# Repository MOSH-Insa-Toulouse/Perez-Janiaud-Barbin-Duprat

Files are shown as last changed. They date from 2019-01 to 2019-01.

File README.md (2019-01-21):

 __   __         _______  _______  __   __ 
|  |_|  |       |       ||       ||  | |  |
|       | ____  |   _   ||  _____||  |_|  |
|       ||____| |  | |  || |_____ |       |
|       |       |  |_|  ||_____  ||       |
| ||_|| |       |       | _____| ||   _   |
|_|   |_|       |_______||_______||__| |__|

/* Presentation of The RC Boat project */

Please make sure that you have all the following file :
	- Arduino Code (.ino)
	- MIT app inventor .apk file
	- 3D plan of the Boat with the .stl extension (made with Fusion360)
	- kicad file for the hardware part
	- Powerpoint presentation
	- Readme.md

/* Boat installation */

1. 3D printing of the different boat part :
	- Keep the proportion between all pieces (we printed the boat with a legnth or 27cm, the maximum possible with our 3D printer)
	- add a hole in the shell, for the motor axe

2. Motor/propeller axis
	- Our best solution was to buy a long metal tube. long enough for the motor to be over the flotation level.
	- The motor axis goes throught the tube. This way the water does not go into the boat
	
3. Rudder control
	- We extended the servomotor axis and added another metal axis to transmit the movement. (see slides)

4. Hardware
	- Follow the Kicad diagramms to place the different part
	- For a better result the PCB shield can be printed
	- Some amelioration can be made :
		- using a more powerfull motor (Brushless for waterproofing and power, ...) 
		- Changing the transistor to a MOSFET to handle higher current
		- Using a tension divider bridge to reduce the tension from 5v to 3.3V on the TX/RX pin of the HC05 BT module

/* Software */
The software is divided into two part:
	- The android application to communicate with the arduino uno and send control for the speed and position
	- The arduino software to recieve the instruction and control the hardware
Both should be used in parralel

/* Credits */
Property of Perez Sarah, Barbin Laure, Janiaud Corentin (with the mental support of Duprat Leo -- Computer Starter and Door Holder --)

 __________________________________
|                                  |
Don't compare your progress
to that of someone else
Everyone works at different speeds
You're doing great and I love you
|__________________________________|
(\__/) ||
(•?•) ||
/   ?

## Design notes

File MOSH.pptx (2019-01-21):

## Projet M-OSH

Bateau Télécommandé

15 janvier 2019
Janiaud Corentin - Perez Sarah - Duprat Léo - Barbin Laure

## Sommaire

- Présentation du projet
- Description Hardware
- Description Software
- Montage du bateau
- Démonstration
- Conclusion

## I - Présentation du Projet

Projet :
Bateau télécommandé par bluetooth
Cahier des charges :
- Bateau + mécanique
- Circuit Hardware (Arduino UNO)
- Application Android de commande
- Software

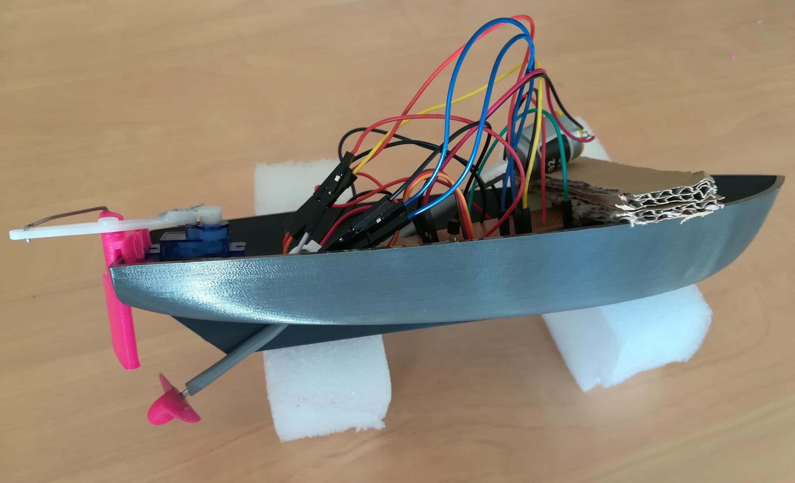
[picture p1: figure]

## II - HARDWARE - COMPOSANTS PRINCIPAUX

Mouvements du bateau :
- Avant
  - Moteur DC
  - Hélice

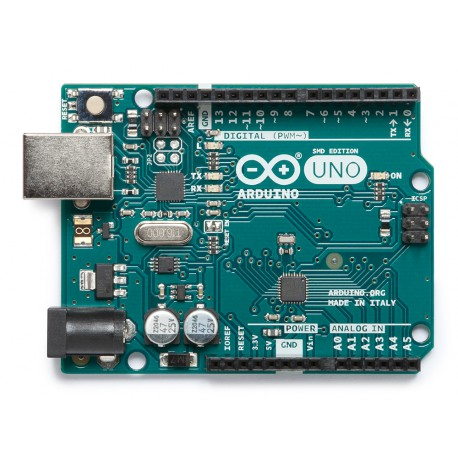
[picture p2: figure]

Arduino UNO

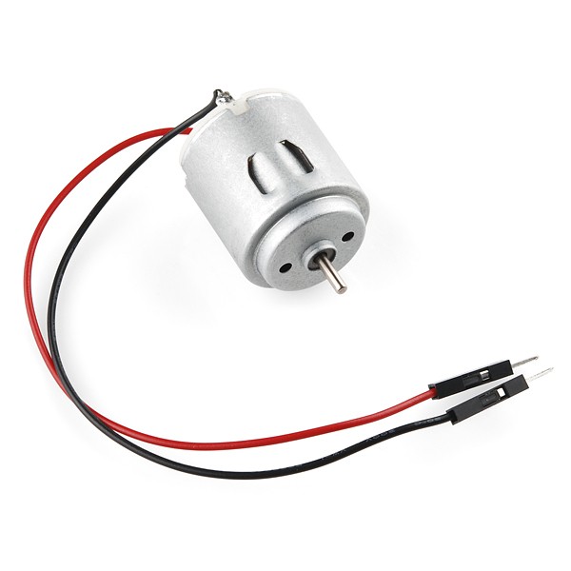
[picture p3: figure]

Moteur DC
⇾ Rotation de l’hélice

## II - HARDWARE - COMPOSANTS PRINCIPAUX

Mouvements du bateau :
- Orientation latérale
  - Gouvernail
  - Servomoteur

Servo-Moteur
⇾ Orientation du gouvernail

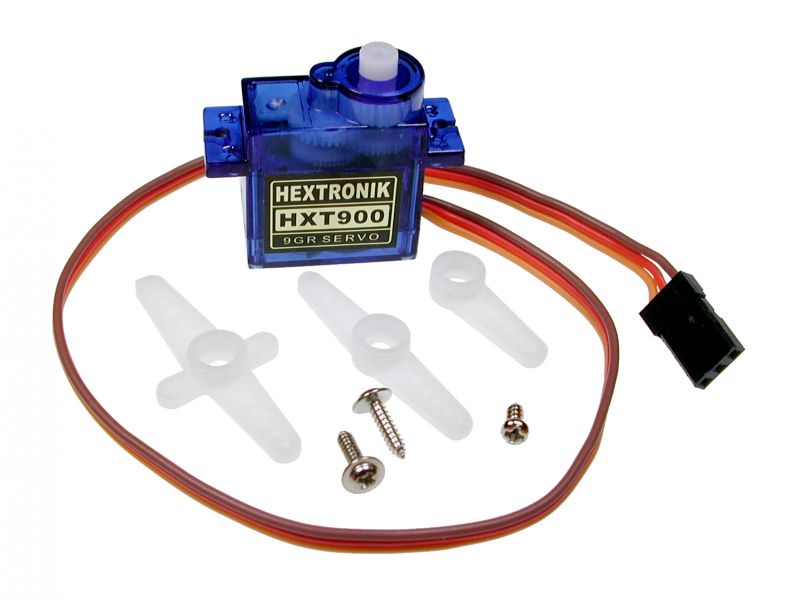
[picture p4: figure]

## II - HARDWARE - COMPOSANTS PRINCIPAUX

Communication avec Android :
- Module Bluetooth

Module HC-05
⇾ Communication bluetooth avec le smartphone

Alimentation embarquée :
- Connecteur pile

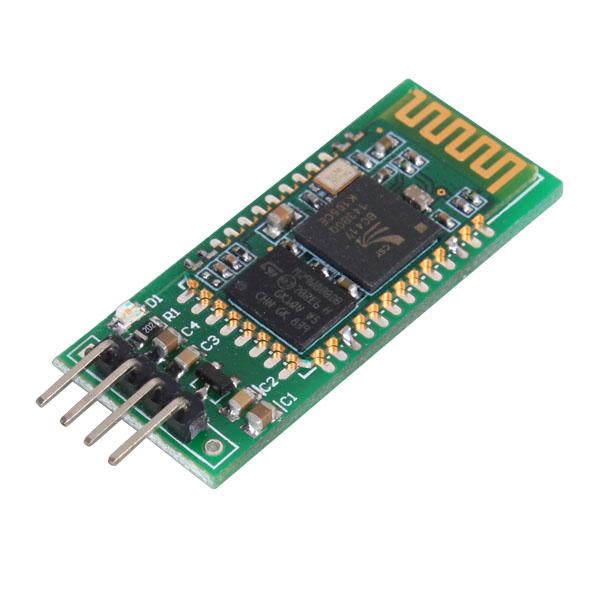
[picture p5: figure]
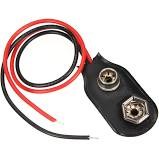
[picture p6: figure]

Connecteur pile 9V
⇾ Alimentation Arduino

## II - HARDWARE - KICAD

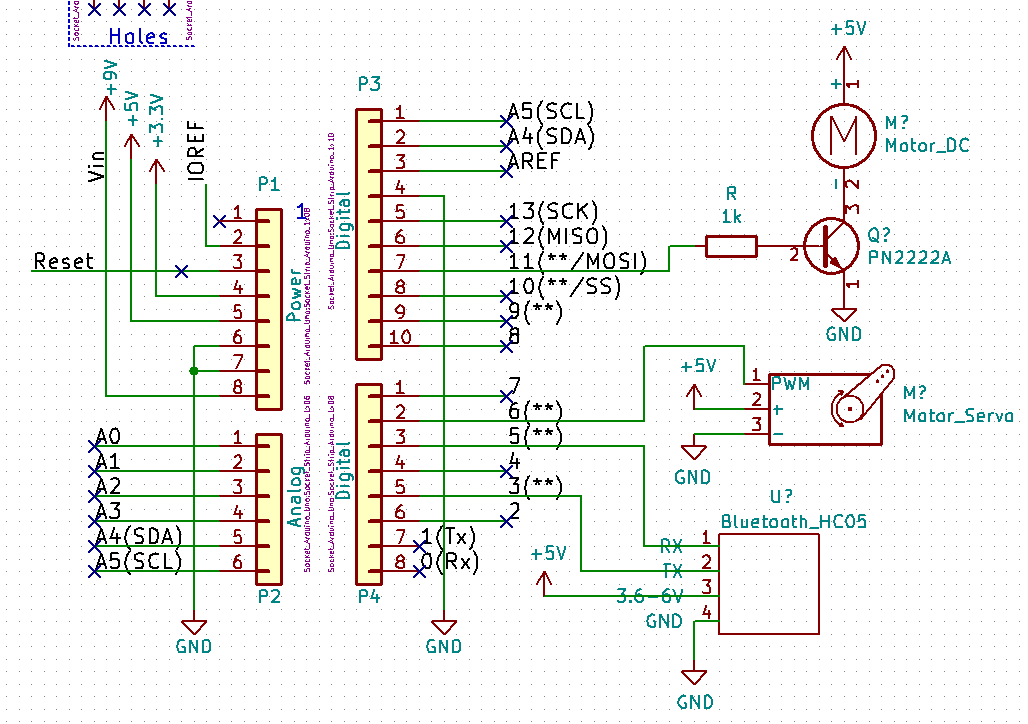
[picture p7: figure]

Mouvement Hélice

Arduino UNO

Mouvement Gouverne

Communication Application

## II - HARDWARE - Circuit

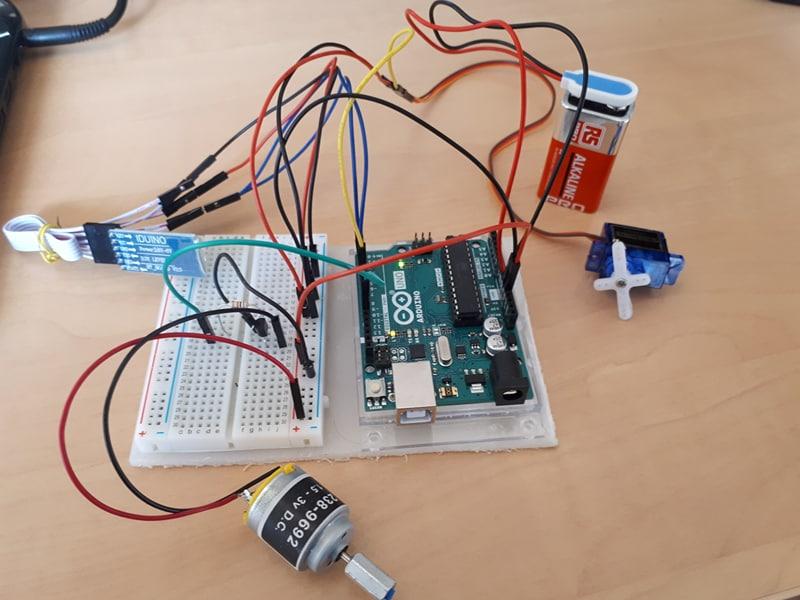
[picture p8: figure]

## III - Software - APPLICATION ANDROID

Fonctionnement application
- Communication avec module Bluetooth
- Démarrage/arrêt bateau
- Vitesse du bateau
- Commande des mouvements latéraux

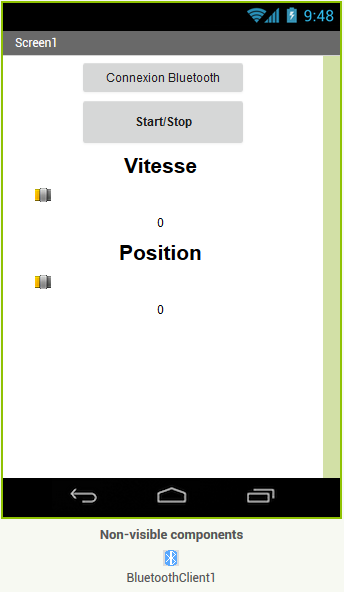
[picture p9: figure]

## III - Software - Code

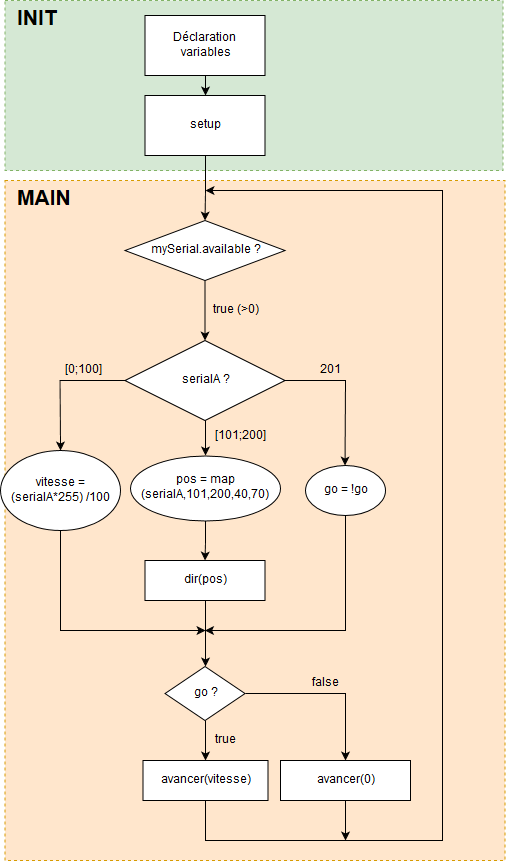
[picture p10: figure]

Logigramme du code Arduino
- Initialisation
- Création port Série
- Récupération des ordres venant de l’application
- Envoi des commandes vers l’hardware

## IV - Montage - Composants 3D printed

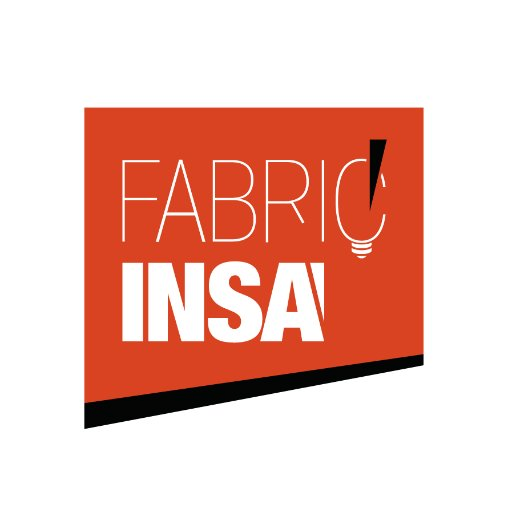
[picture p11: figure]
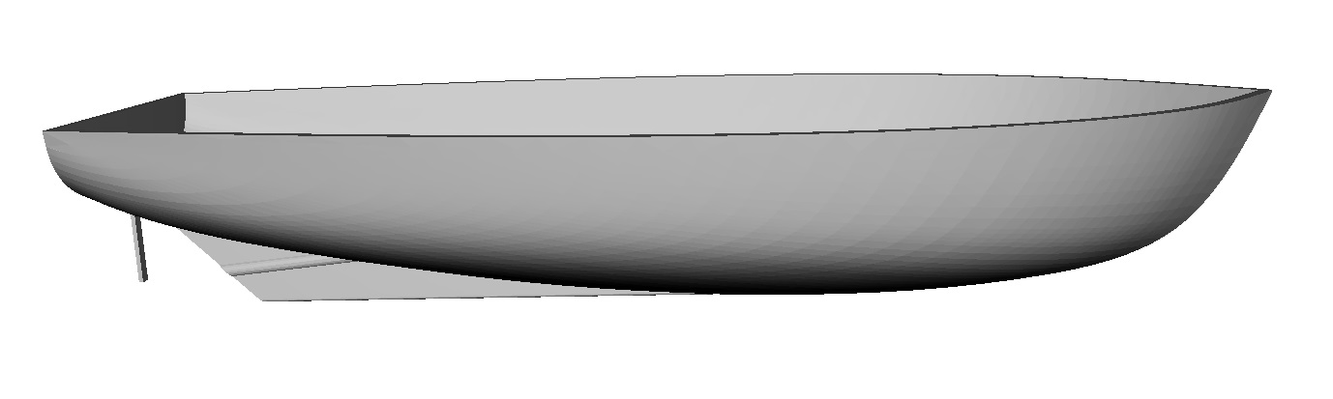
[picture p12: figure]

Coque

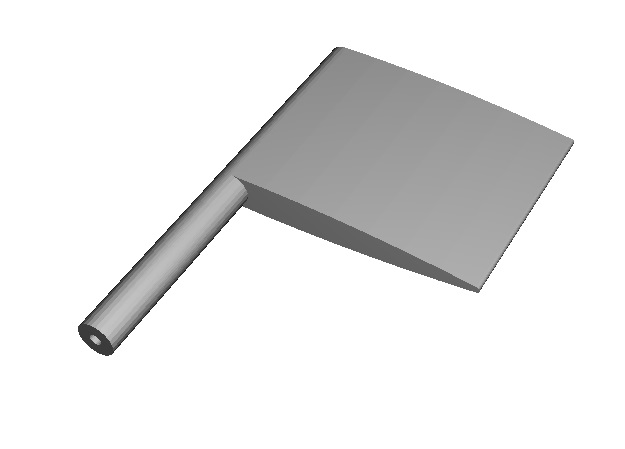
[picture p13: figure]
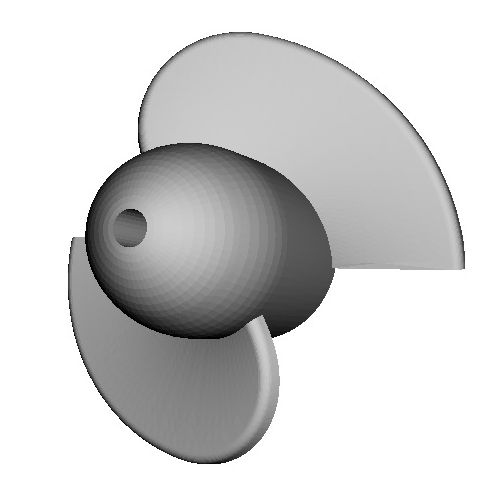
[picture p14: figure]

Hélice (pour avancer)

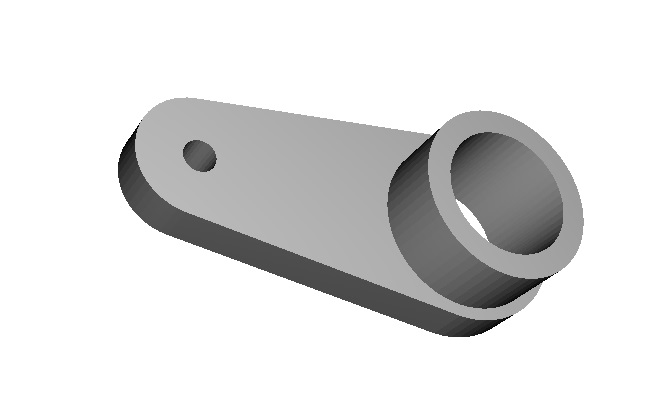
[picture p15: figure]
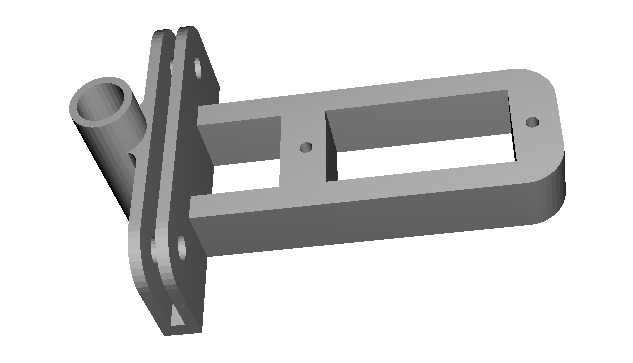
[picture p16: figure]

Eléments du gouvernail (rotation du bateau)

## IV - Montage -> Liaison Gouvernail - ServoMoteur

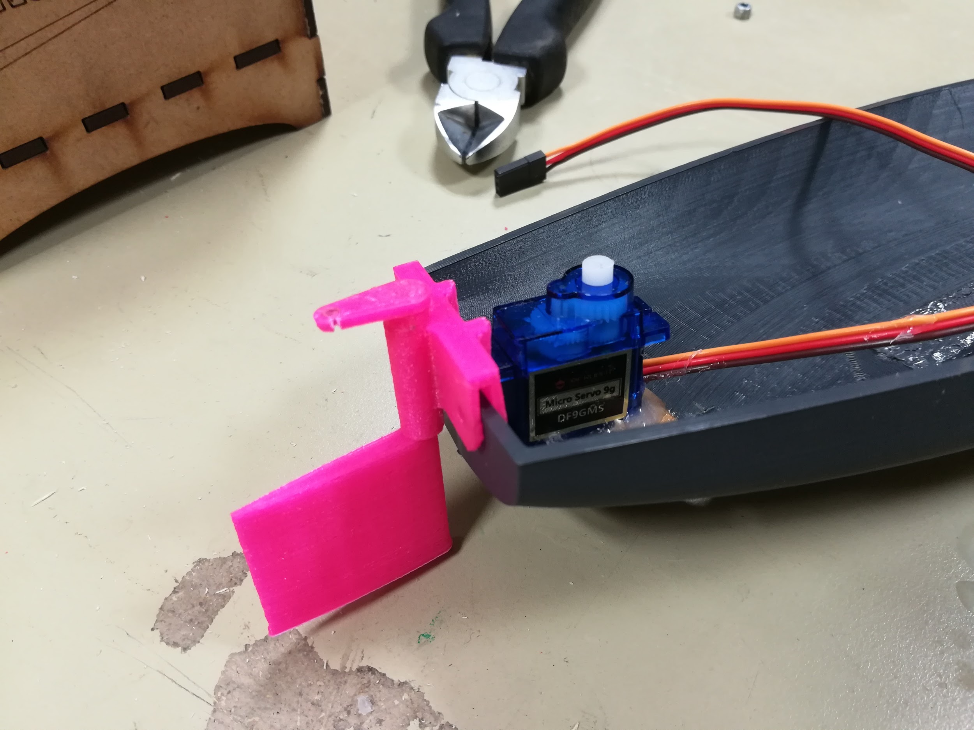
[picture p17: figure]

Problème :
Transmission du mouvement du servomoteur au gouvernail

## IV - Montage -> Liaison Gouvernail - ServoMoteur

- Transmission des mouvements du servomoteur au gouvernail
⤷ 1- Mise en place d’un axe intermédiaire
=> mauvaise transmission, ne couvrant pas toute l’amplitude angulaire
⤷ 2- Double axe intermédiaire

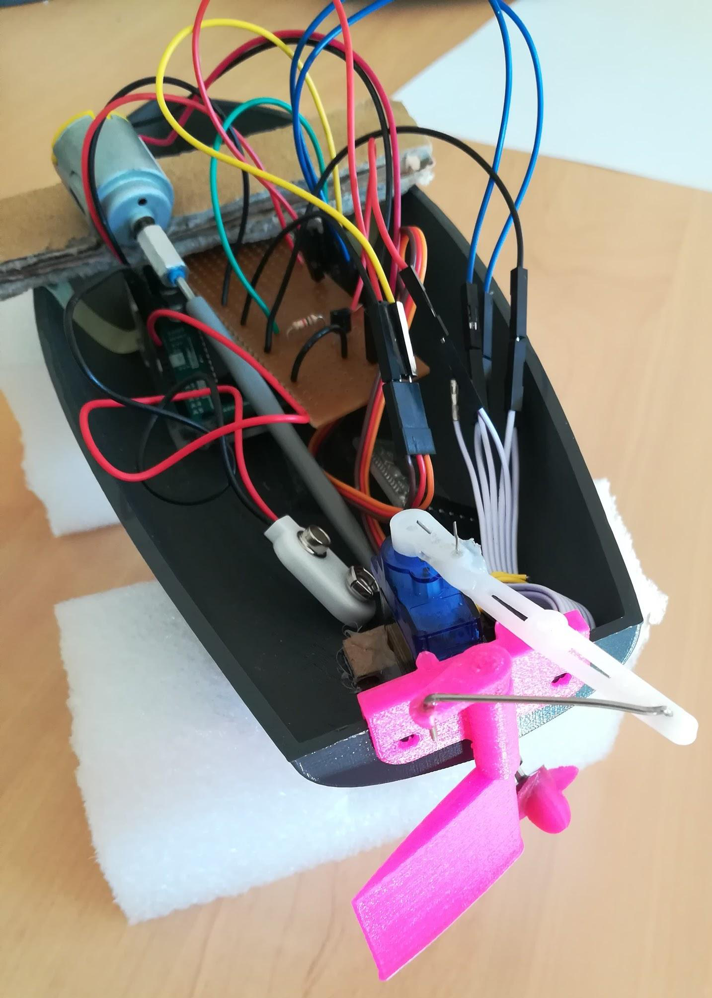
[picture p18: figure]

## IV - Montage - Liaison hélice - Moteur DC

Problème : arbre d’hélice de modélisme trop long.
Solution envisagée : refaire un bateau de 50 cm minimum

27cm

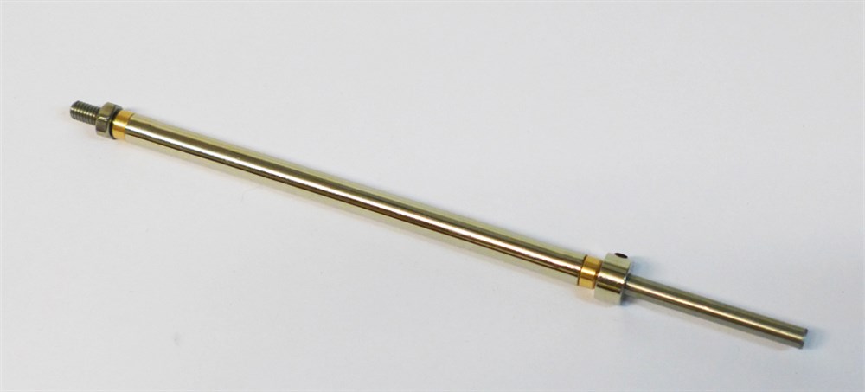
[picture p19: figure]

Arbre hélice
minimum : 20 cm

## IV - Montage - Liaison hélice - Moteur DC

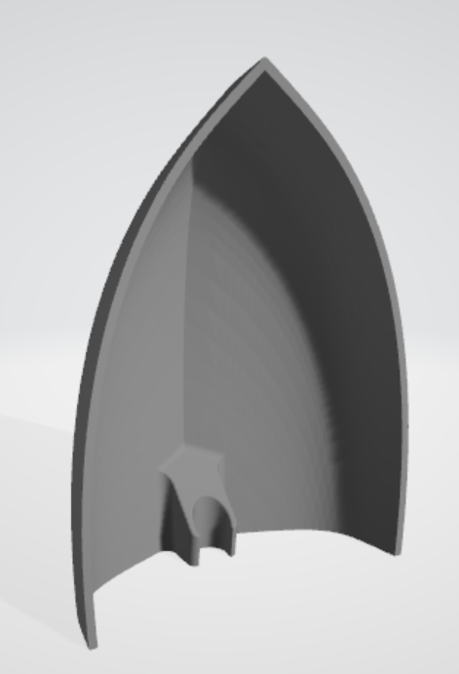
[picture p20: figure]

Création du trou pour l’axe de rotation du moteur

Problèmes :
- temps d’impression (~ 3 jours)
- prix (~ 120 euros)
Solution retenue : se passer de l’arbre “pro”
- Percer un trou dans la coque

Création de 2 pièces
(Fusion 360)

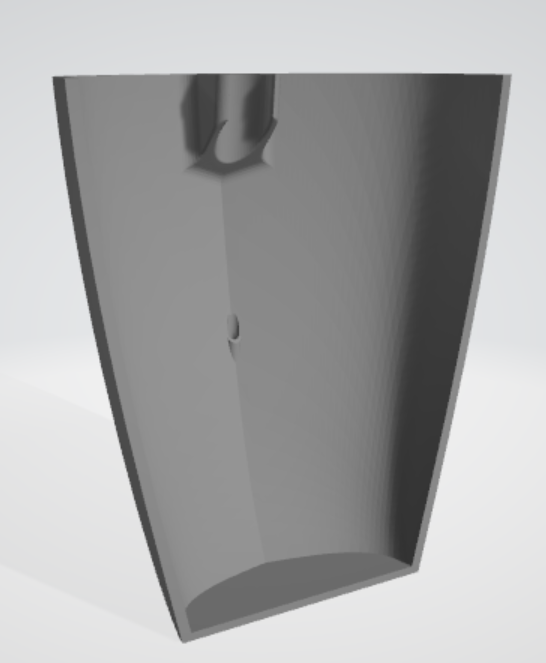
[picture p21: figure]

## IV - Montage -> Liaison hélice - Moteur DC

- Liaison axe et moteur - 1ère solution
⤷ Perçage de la coque
⤷ Insertion d’un axe métallique dans une bague caoutchouc
⤷ Création d’une pièce de liaison Moteur-axe
⤷ Problème de frottements

## IV - Montage -> Liaison hélice - Moteur DC

- Liaison axe et moteur - 2ème solution
⤷ Mise en place de l’axe de rotation dans une gaine en plastique
⤷ Gaine permet de tenir le moteur au-dessus du niveau de flottaison
Problèmes : Toujours frottements
+ Gaine souple => difficultés à maintenir l’axe de rotation droit

## IV - Montage -> Liaison hélice - Moteur DC

- Liaison axe et moteur - 3ème solution
⤷ Remplacer la gaine en plastique par un tube en métal
Suppression des frottements + Axe maintenu + Moteur au dessus du niveau de flottaison

## IV - Montage -> Amélioration de la flottaison

- Répartition du poids dans le bateau
- Surélévation des composants électroniques au dessus du niveau de flottaison
- Ajout de “flotteurs” (liège et/ou polystyrène)
⤷ bouchons collés autour de la coque

## Conclusion

Problèmes rencontrés :
- Mécanique et montage du bateau
  - Manque de de recul
- Test et étanchéité

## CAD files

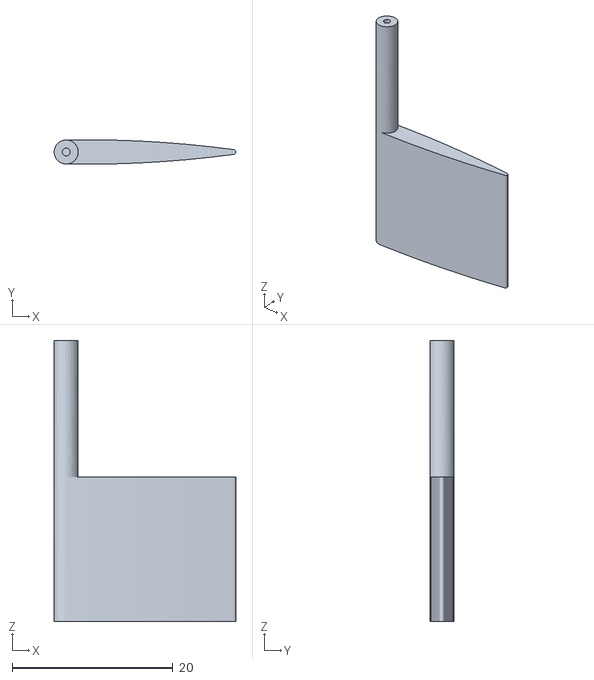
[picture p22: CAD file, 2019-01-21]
.stl files/rudder_with_shaft_small.stl
22.6 x 3.04 x 35.0

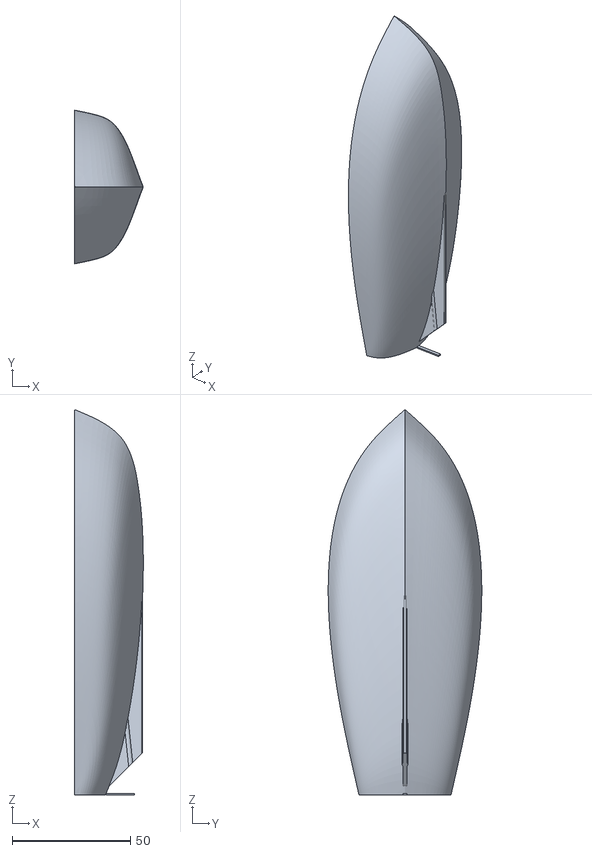
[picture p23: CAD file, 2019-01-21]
.stl files/motor_boat_small.stl
29.0 x 65.0 x 163.0

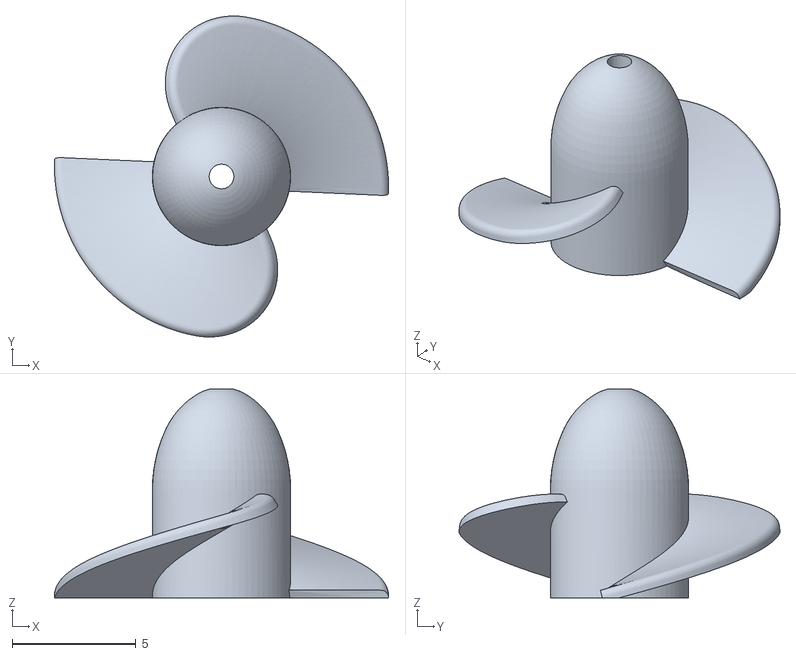
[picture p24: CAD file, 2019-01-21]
.stl files/propeller_small.stl
13.5 x 13.0 x 8.44

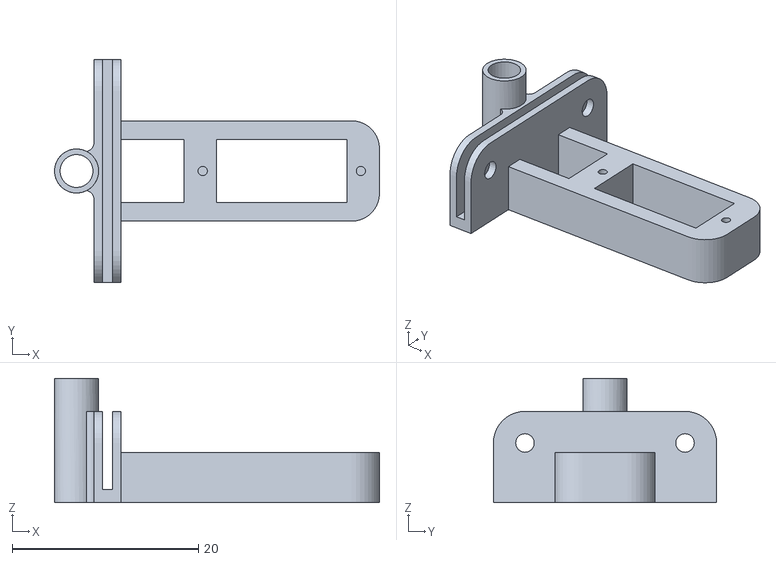
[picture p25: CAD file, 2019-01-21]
.stl files/rudder_mount_small.stl
34.9 x 24.0 x 13.4

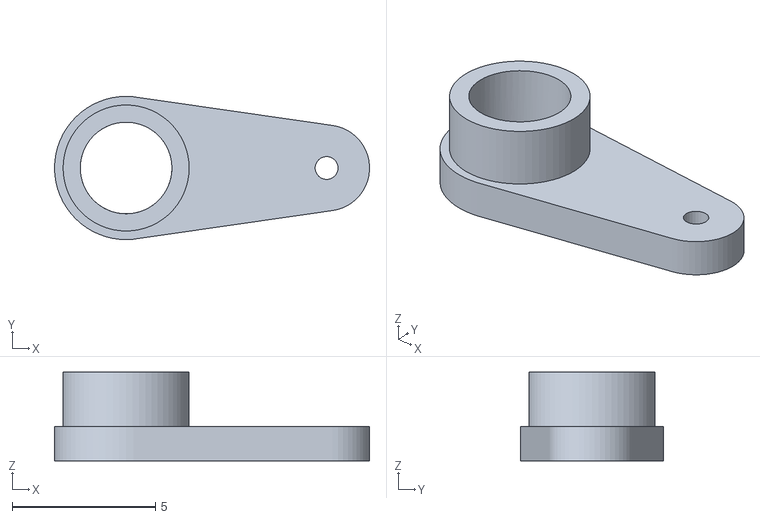
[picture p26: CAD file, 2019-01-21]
.stl files/rudder_horn_small.stl
11.0 x 5.00 x 3.10

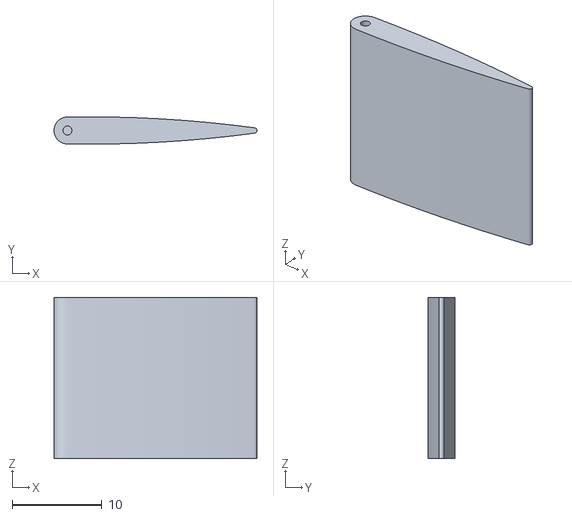
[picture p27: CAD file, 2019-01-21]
.stl files/rudder_small.stl
22.6 x 3.04 x 18.0

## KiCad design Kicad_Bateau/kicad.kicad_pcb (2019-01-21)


Board: 2 copper layers, 68.6 x 53.3 mm, 8 parts (0 on the bottom side), 3 nets, no tracks yet.

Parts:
P1: Power; Socket_Strip_Arduino_1x08
P2: Analog; Socket_Strip_Arduino_1x06
P3: Digital; Socket_Strip_Arduino_1x10
P4: Digital; Socket_Strip_Arduino_1x08
P5, P6, P7, P8: CONN_01X01; Arduino_1pin

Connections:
/A4(SDA): P2.5, P3.2
/A5(SCL): P2.6, P3.1
GND: P1.6, P1.7, P3.4

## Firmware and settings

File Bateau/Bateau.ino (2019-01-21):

/*
pin 11 : moteur
pin 6 : servo
pin 3 : rxPin arduino => TX module BT
pin 5 : txPin arduino => RX module BT
*/


#include <SoftwareSerial.h>
//#include <TimerOne.h>
#include <Servo.h>
#include "Wire.h"

#define rxPin 3
#define txPin 5

Servo myservo ; //création objet "servo"
int serialA=0; // variable de reception de donnée via rxPin
const int speed_serial = 9600; // vitesse communication Bluetooth
SoftwareSerial mySerial(rxPin,txPin); //creation serial BT
int pinMoteur = 11; // moteur pin 11 (PWM)

bool go=false; // variable contrôle start/stop
int vitesse=40; //vitesse moteur (entre 0 et 100)
int pos=90 ; //position servo (angle entre 0 et 180°)

/*  
 *   Configuration du module bluetooth
 */
 /*
void setupBlueToothConnection() // fonction de configuration du module bluetooth
{
  Serial.begin(speed_serial); //vitesse de bluetooth
                              //initialisation de la connexion série (avec le module bluetooth)
//  Serial.print("\r\n+STBD=115200\r\n"); // fixe la vitesse du bluetooth
  Serial.print("\r\n+STBD=9600\r\n"); // fixe la vitesse du bluetooth
  Serial.print("\r\n+STWMOD=0\r\n"); //bluetooth en mode esclave
  Serial.print("\r\n+STNA=Arduino"); //nom de l'appareil
  Serial.print("\r\n+STPIN=0000\r\n");//code pin "0000"
  Serial.print("\r\n+STOAUT=1\r\n"); // Permit Paired device to connect me
  Serial.print("\r\n+STAUTO=0\r\n"); // Auto-connection should be forbidden here
  delay(2000); // This delay is required.
  Serial.print("\r\n+INQ=1\r\n"); //make the slave bluetooth inquirable 
  delay(2000); // This delay is required.
  Serial.flush();
}*/

 
/*
 * setup
 */
 
void setup()
{
  // define pin modes for tx, rx pins:
  pinMode(rxPin,INPUT);
  pinMode(txPin,OUTPUT);
  // ouverture serial
  mySerial.begin(speed_serial);
  //Serial.begin(speed_serial);
  
  myservo.attach(6); //Pin Servo
}


/*
 * main
 */
void loop() {

  //lecture BT uniquement si donnée disponible
  if(mySerial.available()>0) {

    //lecture variable
    serialA=mySerial.read();
    //affichage valeur
    //Serial.print("value : ");
    //Serial.println(serialA);
    
    if (serialA<=100 && serialA>=0){
         // slider vitesse
         vitesse = serialA*255/100;
         //Serial.print("VITESSE :");
         //Serial.println(vitesse);
      }
    else if (serialA>=101 and serialA<=200){
        //slider position
        pos=map(serialA, 101, 200, 70, 110);
        //Serial.print("pos :");
        //Serial.println(pos);
        dir(pos);
      }
    else if (serialA==201){
        //clic_avancer => changement état go to start/stop
        /*if (go==true){
          go=false;
          Serial.println("stop");
        }
        else if (go==false){
          go=true;
          Serial.println("start");
        }*/
        go= (!go);
      }
    /* ancien bouton  
    else if (serialA==202){
        //clicl_reculer
        go=false;
        Serial.println("STOP !!");
      }
    else if (serialA==203){
        //clic_gauche   
        pos-=30;   
        Serial.println("gauche");   
      }
    else if (serialA==204){
        //clic_droit
        pos+=30;
        Serial.println("droite");
      }
    */
    }     

  if (go==true){
    //Serial.print("et c'est parti à ");
    //Serial.print(vitesse);
    //Serial.println(" milliard de km/h");
    avancer(vitesse);
    //dir(pos);
  }
  else {
    avancer(0);
    //dir(pos);
  }
  

 //Serial.print("AT+INQ?\r\n");  
 delay(100);
}



/*
 * Fonction avancer (changement de vitesse moteur)
 */
void avancer(int vitesse)
{
  analogWrite(pinMoteur, vitesse); // réglage vitesse moteur  
}


/*
 * contrôle direction (servo entre 0 et 180°)
 */ 
void dir(int pos)
{
  int pos_act = myservo.read();
  int i=0;
  if (pos_act<pos) {
    for(i = pos_act; i<pos ; i++)  // goes from 0 degrees to 180 degrees
    {                                  // in steps of 1 degree
      myservo.write(i);              // tell servo to go to position in variable 'pos'
      delay(15);                       // waits 15ms for the servo to reach the position
    }
  }
  else if (pos_act>pos) {    
    for(i = pos_act; i>=pos ; i--)  // goes from 0 degrees to 180 degrees
    {                                  // in steps of 1 degree
      myservo.write(i);              // tell servo to go to position in variable 'pos'
      delay(15);                       // waits 15ms for the servo to reach the position
    }
  }
}
  
/*fonction acceleration/decceleration pour un contrôle plus fin de la vitesse
  void accelerer(int vitesse)
  {
    int vitesse_conv = vitesse*255/100 ; //conversion vitesse
    for( int i = 30; i = vitesse_conv; i++ ){
      analogWrite( pinMoteur, i );
      delay(50); // delay pour avoir un progression
    }
  }

void decelerer(int vitesse)
{
  int vitesse_conv = vitesse*255/100 ; //conversion vitesse
  for( int i = vitesse_conv; i > 0; i-- ){
    analogWrite( pinMoteur, i );
    delay(50); // delay pour avoir un progression
  }
}

}*/
